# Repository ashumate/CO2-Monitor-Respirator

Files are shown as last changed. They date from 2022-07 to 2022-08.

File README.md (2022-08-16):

# CO2-Monitor-Respirator

### This is a respirator setup that I made after some coments online that while sites like Etsy have very stylish 'cyberpunk' respirators, none are very functional. This is the first iteration, with future ones planned ...maybe.

### *There may be an issue with the firmware in the repo, if you pull it down and it doesn't work please open an issue and I will re-upload a known working copy*

### The v2 STL files have been modified to add cable strain relief to prefent wires from breaking. 

What you'll need to recreate this version and can give you a jumping off point if you want to create your own.

**WARNING** I am not a developer or designer, just some guy that threw a bunch of parts together and happened to have it all work out, and since actually completing this project from inspiration to design to build am not going to have many excuses for my wife as to why I don't get more done around the house. Share and enjoy!

I created the code by splicing together a lot of other code around the Adafruit and Circuitpython websites and am still tinkering with it. Currently the smileys.bmp file is specific to the DEF CON security conference and will be updated in a future release (maybe, if I get around to it...)

1. A Dentec Comfort-Air NX respirator
2. Adafruit Feather Wing OLED 128x64
3. 2000mAh Lipo battery
4. STEMMA QT 4-pin cable
5. Adafruit SCD-30 NDIR CO2 Sensor
6. Adafruit Feather (The custom Circuitpython in this repo is made for the M4 Express, if you want to use another controller you'll need to re-compile your own per this discussion https://github.com/adafruit/circuitpython/issues/1760)
7. 2 NeoPixel 24 rings
8. A 2.0" 320x240 display
9. A Feather Wing proto board
10. Male, female, and stacking headers for the feather boards
11. The STLs in this repo printed, if you just want a badge that is also a CO2 monitor without a mask you can just print the allinonebadge stl and skip the Neopixels.
12. The custom version of circuitpython from this repo

Hardware to hold items on the badge are M2x6 and M2x8 screws and M2 nuts

Once you've gathered everything together, load the custom boot loader, code and bitmaps, make sure you grab the adafruit circuitpython libraries and put the apropriate ones on the controler. 

Solder the headers onto the controller protoboard and display board

Solder the neopixels to ground, battery out and a digital pin on the proto board and solder the display wires to the proto board. Load up the code and libraries and you should be good to go!

Since I don't have a schematic/wiring/hookup diagram here's how I have things wired

- Protoboard/Feather > Neopixel
- Gnd > Gnd
- Batt > 5VDC In
- D13 > Signal In

- Protoboard/Feather > TFT Display
- GND > GND
- 3V > Vin
- SCK > SCK
- MO > MOSI
- D10 > RST
- D11 > CS
- D12 > D/C

**A note about this, if you want to program the buttons to do things, use pins 9, 10, 11, & 12 for the TFT display and neopixels!**

If you want to make changes to the mounting plate, like add a logo or your social media handles you can access the original in TinkerCad, just dupicate it and modify to your heart's content https://www.tinkercad.com/things/aItuTWLHWLe-co2-monitor-respirator-mounting-plate

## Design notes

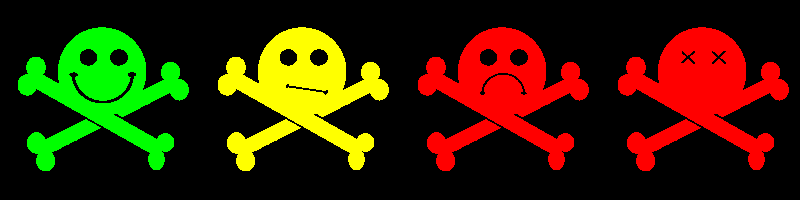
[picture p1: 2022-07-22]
bmps/smileys.bmp

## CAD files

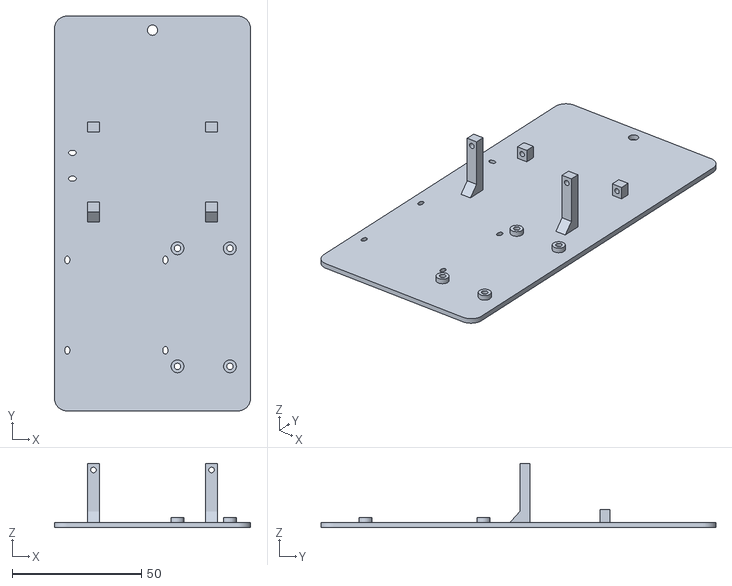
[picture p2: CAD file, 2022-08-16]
sensorandbatterybadge_v2.stl
76.0 x 153.0 x 24.9

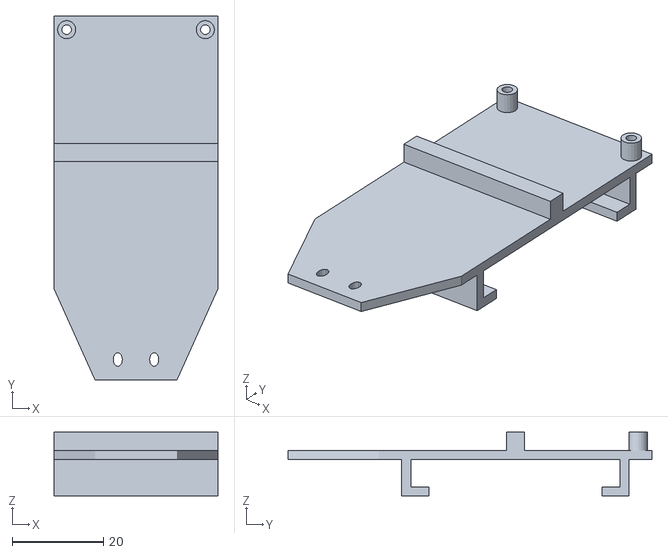
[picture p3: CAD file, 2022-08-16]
maskdisplay_v2.stl
36.0 x 80.0 x 14.0

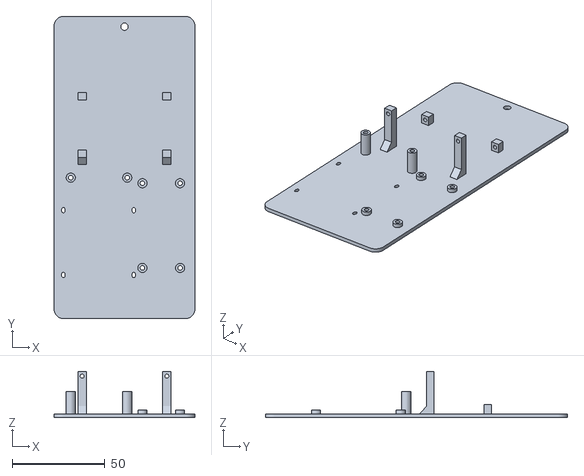
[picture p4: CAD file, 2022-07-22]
allinonebadge.stl
76.0 x 163.0 x 24.9

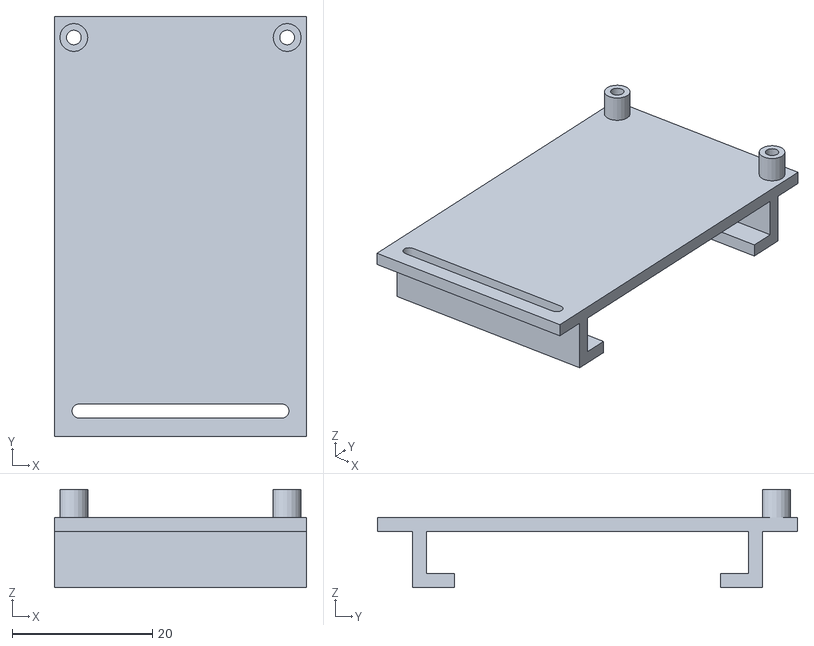
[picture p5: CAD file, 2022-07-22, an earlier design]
maskdisplay.stl
36.0 x 60.0 x 14.0

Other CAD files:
sensorandbatterybadge.stl

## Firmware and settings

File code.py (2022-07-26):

# Drew's CO2 monitoring DEF CON badge/mask
# A lot of this code is taken from other Adafruit code examples, kinda a frankencode...
# Eventually I will use the buttons on the OLED display to do things, like run a calibration routine

import time
import board
import busio
import adafruit_scd30
import displayio
import adafruit_imageload
import terminalio
import adafruit_displayio_sh1107
from adafruit_st7789 import ST7789
from rainbowio import colorwheel
import neopixel
from analogio import AnalogIn
# can try import bitmap_label below for alternative
from adafruit_display_text import bitmap_label

# --| User Config |----
CO2_CUTOFFS = (1000, 2000, 5000)
UPDATE_INTERVAL_SEC = 0.5
MIN_LOOP_DELAY_SEC = 0.0
# ---------------------

# SCD-30 has tempremental I2C with clock stretching, datasheet recommends
# starting at 50KHz
#i2c = busio.I2C(board.SCL, board.SDA, frequency=50000)
scd30 = adafruit_scd30.SCD30(board.I2C())
#scd30.temperature_offset = 0 # thinking of making a separate calibration routine

# Lets get the battery voltage
vbat_voltage = AnalogIn(board.VOLTAGE_MONITOR)

# Let's define some functions
# First let's get the battery voltage
def get_voltage(pin):
    return (pin.value * 3.3) / 65536 * 2

# onboard neopixel color change based on level and blink if over level 4
def pixel0_color(value):
    if scd30.CO2 < CO2_CUTOFFS[0]:
        pixel0.fill((0,255,0))
        pixel0.show()
    elif scd30.CO2 < CO2_CUTOFFS[1]:
        pixel0.fill((255,255,0))
        pixel0.show()
    elif scd30.CO2 < CO2_CUTOFFS[2]:
        pixel0.fill((255,0,0))
        pixel0.show()
    else:
        pixel0.fill((255,0,0))
        pixel0.show()
        time.sleep(0.25)
        pixel0.fill((0,0,0))
        pixel0.show()
        time.sleep(0.25)

# mask neopixel color change based on level and blink if over level 4 Also these are GRBW, not RGBW...
def pixel1_color(value):
    if scd30.CO2 < CO2_CUTOFFS[0]:
        pixel1.fill((255,0,0,0))
        pixel1.show()
    elif scd30.CO2 < CO2_CUTOFFS[1]:
        pixel1.fill((150,255,0,0))
        pixel1.show()
    elif scd30.CO2 < CO2_CUTOFFS[2]:
        pixel1.fill((0,255,0,0))
        pixel1.show()
    else:
        pixel1.fill((40,255,0,0))
        pixel1.show()
        time.sleep(0.5)
        pixel1.fill((0,0,0,0))
        pixel1.show()
        time.sleep(0.125)

# Mask Display update
def update_display(value):

    value = abs(round(value))

    # smiley and label
    if value < CO2_CUTOFFS[0]:
        smiley[0] = label[0] = 0
    elif value < CO2_CUTOFFS[1]:
        smiley[0] = label[0] = 1
    elif value < CO2_CUTOFFS[2]:
        smiley[0] = label[0] = 2
    else:
        smiley[0] = label[0] = 3

    # CO2 value
    # clear it
    for i in range(4):
        co2_value[i] = 10
    # update it
    i = 3
    while value:
        co2_value[i] = value % 10
        value = int(value / 10)
        i -= 1

# release any currently configured displays
displayio.release_displays()

# setup fourwire for TFT display
# if the mask display isn't working verify the cs dc and reset pins, this has flumoxed me
spi = board.SPI()
tft_cs = board.D11
tft_dc = board.D12

# setup displays
display_bus0 = displayio.I2CDisplay(board.I2C(), device_address=0x3C)
display_bus1 = displayio.FourWire(
     spi, command=tft_dc, chip_select=tft_cs, reset=board.D10
)

# Define the first display
# SH1107 is vertically oriented 64x128 set as display0
display0 = adafruit_displayio_sh1107.SH1107(
    display_bus0, width=128, height=64, rotation=0
)

# Lets give display0 some output
# create labels and do some math
co2 = "CO2: %d PPM" % scd30.CO2
#temperature = "Temp: %0.2f Degrees F" % ((scd30.temperature* 9/5) + 32)
temperature = "Temp: %0.2f Degrees C" % scd30.temperature
humidity = "Humidity: %0.2f %% rH" % scd30.relative_humidity
battery_voltage = "Batt: %0.2f VDC" % get_voltage(vbat_voltage)

# Draw some label text
co2_line = bitmap_label.Label(terminalio.FONT, text=co2, scale=1, color=0xFFFFFF, x=2, y=4)
temp_line = bitmap_label.Label(terminalio.FONT, text=temperature, scale=1, color=0xFFFFFF, x=2, y=19)
humidity = bitmap_label.Label(terminalio.FONT, text=humidity, scale=1, color=0xFFFFFF, x=2, y=34)
battery_voltage = bitmap_label.Label(terminalio.FONT, text=battery_voltage, scale=1, color=0xFFFFFF, x=2, y=49)

# Make the display context and show the data
splash0 = displayio.Group()
splash0.append(co2_line)
splash0.append(temp_line)
splash0.append(humidity)
splash0.append(battery_voltage)
display0.show(splash0)

# # define second display
display1 = ST7789(display_bus1, width=240, height=320, rotation=180)

# Let's put some content on Display1
# current condition smiley face
smileys_bmp, smileys_pal = adafruit_imageload.load("/bmps/smileys.bmp")
smiley = displayio.TileGrid(
    smileys_bmp,
    pixel_shader=smileys_pal,
    x=20,
    y=0,
    width=1,
    height=1,
    tile_width=200,
    tile_height=200,
)
#Like co2line above but we want bigger text
co2_label = bitmap_label.Label(terminalio.FONT, text="CO2 PPM", scale=4, color=0xFFFFFF)
co2_label.anchor_point = (0.5, 0.5)
co2_label.anchored_position = (120, 220)
co2_level = bitmap_label.Label(terminalio.FONT, text="%d" % scd30.CO2, scale=6, color=0xFFFFFF)
co2_level.anchor_point = (0.5, 0.5)
co2_level.anchored_position = (120, 275)

# Lets setup display1 context and show the data
splash1 = displayio.Group()
splash1.append(smiley)
splash1.append(co2_label)
splash1.append(co2_level)
display1.show(splash1)

# setup neopixels
# onboard neopixel
pixel0 = neopixel.NeoPixel(board.NEOPIXEL, 1, brightness=0.01)
# mask neopixels
# uncomment when connected dont forget to set pin...
pixel1 = neopixel.NeoPixel(board.D13, 48, pixel_order=neopixel.RGBW, brightness=0.01)

next_update_time = time.time()

# Let's light this candle
while True:
    #Update onboard display values
    co2_line.text = "CO2: %d PPM" % scd30.CO2
    #temp_line.text = "Temp: %0.2f Degrees F" % ((scd30.temperature* 9/5) + 32)
    temp_line.text = "Temp: %0.2f Degrees C" % scd30.temperature
    humidity.text = "Humidity: %0.2f %% rH" % scd30.relative_humidity
    battery_voltage.text = "Batt: %0.2f VDC" % get_voltage(vbat_voltage)
    co2_level.text = "%d" % scd30.CO2
    pixel0_color(scd30.CO2)
    pixel1_color(scd30.CO2)
    # protect against NaNs and Nones
    try:
        update_display(scd30.CO2)

    except:
        pass
    next_update_time += UPDATE_INTERVAL_SEC
    time.sleep(max(next_update_time - time.time(), MIN_LOOP_DELAY_SEC))

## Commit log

2022-07-20 Add files via upload
    Circuitpython firmware modified to allow two displays on a Feather M4 Express
2022-07-24 Modify loop timing
    Modifies the loop timing to achieve the configured rate regardless of loop processing time. If the loop takes longer than UPDATE_INTERVAL_SEC, the delay between loops will always be at least MIN_LOOP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
    Tested in python3 on my desktop.
2022-07-24 Fixed display pins and a spelling issue
    [code.py]
2022-08-16 Added new versions of display and badge parts
    While wearing the mask around DEF CON one of the wires broke and needed some soldering done. This is because I didn't think to add any cable strain relief. That has been added to these versions of the printables.
    [maskdisplay_v2.stl, sensorandbatterybadge_v2.stl]
